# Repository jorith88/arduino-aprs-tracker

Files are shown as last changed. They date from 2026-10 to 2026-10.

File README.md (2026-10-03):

# arduino-aprs-tracker

Arduino APRS Tracker based on libAPRS with SmartBeaconing

## Hardware
* Arduino Pro Mini 3.3V 8 MHz https://www.adafruit.com/products/2377
* Adafruit Ultimate GPS https://www.adafruit.com/product/746
* or any GPS that can output NMEA (NEO-6M is tested with some minor issues)

## Libraries
* TinyGPS http://arduiniana.org/libraries/tinygps/
* libAPRS (modified) https://github.com/billygr/LibAPRS

## Notes
There are cases where the NEO-6M displays wrong data such as course/altitude. I have trace it to the interrupt of ADC (needed for APRS).
When the interrupt is fired, disrupts the SoftwareSerial so it looses GPS messages.
By default NEO-6M has these messages enabled GSV, RMC, GSA, GGA, GLL, VTG, TXT. 
The GLL is not needed so it is disabled on power on. If you still have issues enable the define, it will switch the NEO-6M on 4800 baud which looks like it fixes it

## Ignore configuration changes
To ignore changes to configuration.h in Git, execute the following command:
```
git update-index --assume-unchanged arduino-aprs-tracker/configuration.h
```

To start tracking changes again:
```
git update-index --no-assume-unchanged arduino-aprs-tracker/configuration.h
```

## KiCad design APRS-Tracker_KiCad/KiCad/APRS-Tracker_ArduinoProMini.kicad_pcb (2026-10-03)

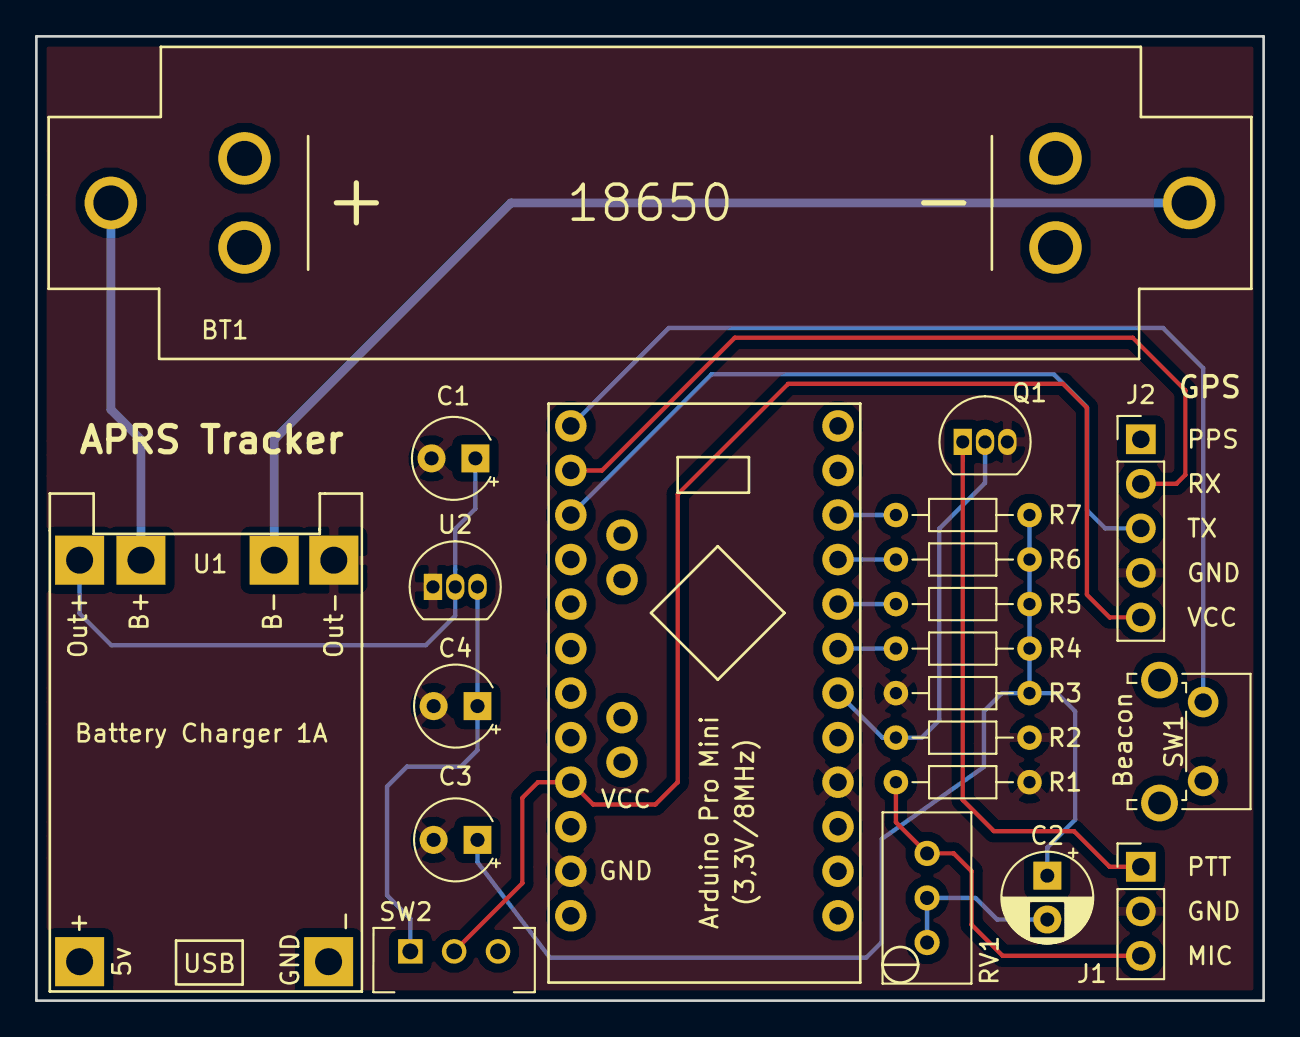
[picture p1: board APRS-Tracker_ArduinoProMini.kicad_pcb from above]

Board: 2 copper layers, 70.0 x 55.0 mm, 21 parts (0 on the bottom side), 18 nets.

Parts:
BT1: Battery_Cell; Battery_ClipHolder_18650
C1, C4: 1uF; CP_Radial_Tantal_D4.5mm_P2.50mm
C2: 4,7uF/16V; CP_Radial_D5.0mm_P2.50mm
C3: 100nF; CP_Radial_Tantal_D4.5mm_P2.50mm
J1: Conn_01x03_Male; PinHeader_1x03_P2.54mm_Vertical
J2: Conn_01x05_Male; PinHeader_1x05_P2.54mm_Vertical
Q1: BS170; TO-92_Inline
R1, R7: 1k; R_Axial_DIN0204_L3.6mm_D1.6mm_P7.62mm_Horizontal
R2: 10k; R_Axial_DIN0204_L3.6mm_D1.6mm_P7.62mm_Horizontal
R3: 270; R_Axial_DIN0204_L3.6mm_D1.6mm_P7.62mm_Horizontal
R4: 8,2k; R_Axial_DIN0204_L3.6mm_D1.6mm_P7.62mm_Horizontal
R5: 3,9k; R_Axial_DIN0204_L3.6mm_D1.6mm_P7.62mm_Horizontal
R6: 2,2k; R_Axial_DIN0204_L3.6mm_D1.6mm_P7.62mm_Horizontal
RV1: 10k; Potentiometer_Bourns_3296W_Vertical
SW1: SW_Push; SW_Tactile_SPST_Angled_PTS645Vx31-2LFS
SW2: SW_SPDT; SW_CuK_JS202011BQN_SPDT_Angled
U1: TP4056; TP4056-18650
U2: MCP1700-3302E_TO92; TO-92_Inline
U3: Arduino-Pro-Mini; Arduino-ProMini

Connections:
+3V3: J2.5, SW2.2, U3.21
/MIC_ANALOG_OUT: J1.3, R1.2, RV1.3
/PTT: J1.1, Q1.1
/PTT_IN: Q1.2, R2.1, U3.6
/RX: J2.2, U3.14
/TX: J2.3, U3.15
GND: C1.2, C3.2, C4.2, J1.2, J2.4, Q1.3, R1.1, R2.2, R3.1, SW1.2, U1.4, U2.1, U3.4, U3.23
unnamed: BT1.1, U1.5
unnamed: BT1.2, U1.6
unnamed: C1.1, U1.3, U2.2
unnamed: C2.1, C3.1, R3.2, R4.2, R5.2, R6.2, R7.2
unnamed: C2.2, RV1.1, RV1.2
unnamed: C4.1, SW2.1, U2.3
unnamed: R4.1, U3.7
unnamed: R5.1, U3.8
unnamed: R6.1, U3.9
unnamed: R7.1, U3.10
unnamed: SW1.1, U3.13

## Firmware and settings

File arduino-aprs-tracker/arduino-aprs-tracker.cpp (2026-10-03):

/***
 * Arduino APRS Tracker (aat) with Arduino Pro Mini 3.3V/8 MHz
 * Install the following libraries
 * - TinyGPSPlus by Mikal Hart https://github.com/mikalhart/TinyGPSPlus
 * - LibAPRS (modified) https://github.com/billygr/libaprs
 * -
 ***/

#include <Arduino.h>
#include <SoftwareSerial.h>
#include "src/SimpleTimer/SimpleTimer.h"
#include <TinyGPS++.h>
#include <LibAPRS.h>
#include "configuration.h"

// Manual update button
#define BUTTON_PIN 10

// GPS SoftwareSerial
// Shares pins with (MISO 12/ MOSI 11) used for SPI
#define GPS_RX_PIN 12
#define GPS_TX_PIN 11
TinyGPSPlus gps;
SoftwareSerial GPSSerial(GPS_RX_PIN, GPS_TX_PIN);

// LibAPRS
#define OPEN_SQUELCH false
#define ADC_REFERENCE REF_3V3


// PPT_PIN is defined on libAPRS/device.h
//#define PPT_PIN 3

// GPS_FIX_LED A3/D17
#define GPS_FIX_LED A3

//long instead of float for latitude and longitude, TinyGPSPlus needs double
double lat = 0;
double lon = 0;

int speed_kt = 0;
int currentcourse=0;
int ialt=0;

int year=0;
byte month=0, day=0, hour=0, minute=0, second=0;
unsigned long age=0;

int altm=0;
float fkmph=0;

unsigned long lastTX =0, tx_interval= 0;

int previouscourse = 0, turn_threshold = 0, courseDelta = 0;

// set when the manual update button was pressed, handled once we have a fix
bool buttonPressed = false;

// max time to wait for LibAPRS to finish transmitting
#define TX_TIMEOUT_MS 10000UL

// buffer for conversions
#define CONV_BUF_SIZE 16
static char conv_buf[CONV_BUF_SIZE];

char* deg_to_nmea(long deg, boolean is_lat);
void locationUpdate();

/*****************************************************************************************/
void setup()
{
  Serial.begin(115200);
  GPSSerial.begin(9600);

  pinMode(BUTTON_PIN, INPUT_PULLUP);
  pinMode(GPS_FIX_LED,OUTPUT);

  if (SERIAL_LOG_OUTPUT) {
    Serial.println(F("Arduino APRS Tracker"));
  }

  // uncomment this line to turn on RMC (recommended minimum) and GGA (fix data) including altitude
  //GPS.sendCommand(PMTK_SET_NMEA_OUTPUT_RMCGGA);

  // 1 Hz update rate, not needed for an APRS Tracker
  //GPS.sendCommand(PMTK_SET_NMEA_UPDATE_1HZ);

  // Request updates on antenna status, keep it disabled
  //GPS.sendCommand(PGCMD_ANTENNA);

  APRS_init(ADC_REFERENCE, OPEN_SQUELCH);
  APRS_setCallsign(APRS_CALLSIGN,APRS_SSID);
  APRS_setSymbol(APRS_SYMBOL);
  
}

/*****************************************************************************************/
void loop()
{
  bool newData = false;
  
  // For one second we parse GPS data
  for (unsigned long start = millis(); millis() - start < 1000;)
  {
    while (GPSSerial.available())
    {
      char c = GPSSerial.read();
      if (SERIAL_LOG_OUTPUT) {
        Serial.write(c); // uncomment this line if you want to see the GPS data flowing
      }
      if (gps.encode(c)) // Did a new valid sentence come in?
       newData = true;
    }

    // Poll the button continuously so short presses are not missed
    if (!buttonPressed && digitalRead(BUTTON_PIN) == LOW)
    {
      delay(30); // debounce
      if (digitalRead(BUTTON_PIN) == LOW) buttonPressed = true;
    }
  }

  if (newData)
  {
    year=gps.date.year();
    month=gps.date.month();
    day=gps.date.day();
    hour=gps.time.hour();
    minute=gps.time.minute();
    second=gps.time.second();

    lat=gps.location.lat()*1000000;
    lon=gps.location.lng()*1000000;

    altm = int(gps.altitude.meters()); // integer value of altitude in meters
    ialt = int(gps.altitude.feet());  // integer value of altitude in feet

    fkmph = gps.speed.kmph(); // speed in km/hs

    speed_kt = (int) gps.speed.knots();

    currentcourse = (int) gps.course.deg();

    // Calculate difference of course to smartbeacon
    courseDelta = (int) ( previouscourse - currentcourse );
    courseDelta = abs (courseDelta);
    if (courseDelta > 180) {
      courseDelta = courseDelta - 360;
    }
    courseDelta = abs (courseDelta) ;

    age = gps.location.age();
    if (!gps.location.isValid()) {
      if (SERIAL_LOG_OUTPUT) {
        Serial.println(F("No fix detected"));
      }
      buttonPressed = false;
      return;
    } else if (age > 5000) {
      // Never transmit a stale position
      if (SERIAL_LOG_OUTPUT) {
        Serial.println(F("Warning: stale data, not transmitting"));
      }
      buttonPressed = false;
      return;
    } else {
      if (SERIAL_LOG_OUTPUT) {
        Serial.println(F("Data is current."));
      }
      digitalWrite(GPS_FIX_LED, !digitalRead(GPS_FIX_LED)); // Toggles the GPS FIX LED on/off
    }


    if (SERIAL_LOG_OUTPUT) {
      Serial.print(static_cast<int>(day)); Serial.print(F("/")); Serial.print(static_cast<int>(month)); Serial.print(F("/")); Serial.print(year);
      Serial.print(F(" ")); Serial.print(static_cast<int>(hour)); Serial.print(F(":")); Serial.print(static_cast<int>(minute)); Serial.print(F(":")); Serial.print(static_cast<int>(second));
      Serial.print(F(" "));
      Serial.print(F("LAT="));Serial.print(lat);
      Serial.print(F(" LON="));Serial.print(lon);
      Serial.print(F(" "));
      Serial.print(deg_to_nmea(lat, true));
      Serial.print(F("/"));
      Serial.print(deg_to_nmea(lon, false));
      Serial.print(F(" Altitude m/ft: ")); Serial.print(altm);Serial.print(F("/"));Serial.println(ialt);
    }

    if (buttonPressed)
    {
      buttonPressed = false;
      while(digitalRead(BUTTON_PIN)==0) {}; // wait for release
      if (SERIAL_LOG_OUTPUT) {
        Serial.println(F("MANUAL UPDATE"));
      }
      locationUpdate();
      lastTX = millis();
    }
  
    // Based on HamHUB Smart Beaconing(tm) algorithm
    if ( fkmph < LOW_SPEED ) {
      tx_interval = SLOW_RATE *1000L;
    }
    else if ( fkmph > HIGH_SPEED) {
      tx_interval = FAST_BEACON_RATE  *1000L;
    }
    else {
    // Interval inbetween low and high speed
    // float math: FAST_BEACON_RATE * HIGH_SPEED overflows a 16-bit int
    tx_interval = (unsigned long) (((float) FAST_BEACON_RATE * HIGH_SPEED) / fkmph * 1000.0f);
    }

    // Course is noise at low speed and TURN_SLOPE / fkmph divides by zero when standing still
    if (fkmph >= TURN_MIN_SPEED) {
      turn_threshold = TURN_MIN + TURN_SLOPE / fkmph;
    } else {
      turn_threshold = 360;
    }

    if (courseDelta > turn_threshold ){
      if ( millis() - lastTX > MIN_TURN_TIME *1000L){
        if (SERIAL_LOG_OUTPUT) {
          Serial.println(F("APRS UPDATE"));
        }
        locationUpdate();
        lastTX = millis();
      }
    }

    previouscourse = currentcourse;

    if ( millis() - lastTX > tx_interval) {
      if (SERIAL_LOG_OUTPUT) {
        Serial.println(F("APRS UPDATE"));
      }
      locationUpdate();
      lastTX = millis();
    }

  }

}

/*****************************************************************************************/
void aprs_msg_callback(struct AX25Msg *msg) {
}

/*****************************************************************************************/
void locationUpdate() {
//Altitude in Comment Text — The comment may contain an altitude value,
//in the form /A=aaaaaa, where aaaaaa is the altitude in feet. For example:
//A=001234. The altitude may appear anywhere in the comment.
//Source: APRS protcol

  char temp[8];
  char APRS_comment[3 + 6 + sizeof(APRS_COMMENT)] = "/A=";

  // Convert altitude in string and pad left
  sprintf(temp, "%06d", ialt);
  strcat(APRS_comment,temp);
  strcat(APRS_comment,APRS_COMMENT);
  if (SERIAL_LOG_OUTPUT) {
    Serial.println(APRS_comment);
  }

  APRS_setLat((char*)deg_to_nmea(lat, true));
  APRS_setLon((char*)deg_to_nmea(lon, false));

  APRS_setSpeed(speed_kt);
  APRS_setCourse(currentcourse);

  // turn off SoftSerial to stop interrupting tx
  GPSSerial.end();


  // TX
  APRS_sendLoc(APRS_comment, strlen(APRS_comment));

  // read TX LED pin and wait till TX has finished. LibAPRS has TX_LED defined on (PB5), i use LED_BUILTIN on my version as TX_LED
  // (with a timeout so a stuck pin can't hang the tracker)
  for (unsigned long start = millis(); digitalRead(LED_BUILTIN) && millis() - start < TX_TIMEOUT_MS;) {}

  // start SoftSerial again
  GPSSerial.begin(9600);
}

/*****************************************************************************************/
/*
**  Convert degrees in long format to APRS string format
**  DDMM.hhN for latitude and DDDMM.hhW for longitude
**  D is degrees, M is minutes and h is hundredths of minutes.
**  http://www.aprs.net/vm/DOS/PROTOCOL.HTM
*/
char* deg_to_nmea(long deg, boolean is_lat) {
  bool is_negative=0;
  if (deg < 0) is_negative=1;

  // Use the absolute number for calculation and update the buffer at the end
  deg = labs(deg);

  unsigned long b = (deg % 1000000UL) * 60UL;
  unsigned long a = (deg / 1000000UL) * 100UL + b / 1000000UL;
  b = (b % 1000000UL) / 10000UL;

  conv_buf[0] = '0';
  // in case latitude is a 3 digit number (degrees in long format)
  if( a > 9999) {
    snprintf(conv_buf , 6, "%04lu", a);
  } else {
    snprintf(conv_buf + 1, 5, "%04lu", a);
  }

  conv_buf[5] = '.';
  snprintf(conv_buf + 6, 3, "%02lu", b);
  conv_buf[9] = '\0';
  if (is_lat) {
    if (is_negative) {conv_buf[8]='S';}
    else conv_buf[8]='N';
    return conv_buf+1;
    // conv_buf +1 because we want to omit the leading zero
    }
  else {
    if (is_negative) {conv_buf[8]='W';}
    else conv_buf[8]='E';
    return conv_buf;
    }
}

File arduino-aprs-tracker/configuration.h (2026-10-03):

// Symbols
#define SYMBOL_BIKE 'b'
#define SYMBOL_CAR '>'
#define SYMBOL_RUNNER '['
#define SYMBOL_LARO 'j'
#define SYMBOL_SCOUTING ','

// APRS settings
char APRS_CALLSIGN[] = "PA3JH";
const int APRS_SSID = 7;
char APRS_SYMBOL = SYMBOL_RUNNER;
char APRS_COMMENT[] = "PA3WWE/J Scouting Wielewaal";

// SmartBeaconing(tm) Setting  http://www.hamhud.net/hh2/smartbeacon.html implementation by LU5EFN
#define LOW_SPEED 999 // [km/h]
#define HIGH_SPEED 9999

#define SLOW_RATE 60 // [seg]
#define FAST_BEACON_RATE  60

#define TURN_MIN  30
#define TURN_SLOPE  240
#define MIN_TURN_TIME 20
#define TURN_MIN_SPEED 5 // [km/h] below this no turn beacons

// Debug settings
#define SERIAL_LOG_OUTPUT false

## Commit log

2022-08-25 small changes
    [configuration.h]
2026-10-03 Fix tracker bugs found in review
    - Skip turn beacons below TURN_MIN_SPEED (division by zero when standing still)
    - Add timeout when waiting for TX to finish
    - Do not transmit stale GPS positions
    - Fix 16-bit overflow in smart beacon interval
    - Poll manual update button continuously with debounce, reset lastTX after manual TX
    [configuration.h]
2026-10-03 Update APRS settings and symbols in configuration.h
    [configuration.h]
